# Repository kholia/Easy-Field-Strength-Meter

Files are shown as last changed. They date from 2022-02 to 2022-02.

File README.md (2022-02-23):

### Easy-Field-Strength-Meter

Jan-2022 UPDATE: v2 is published which works much better.

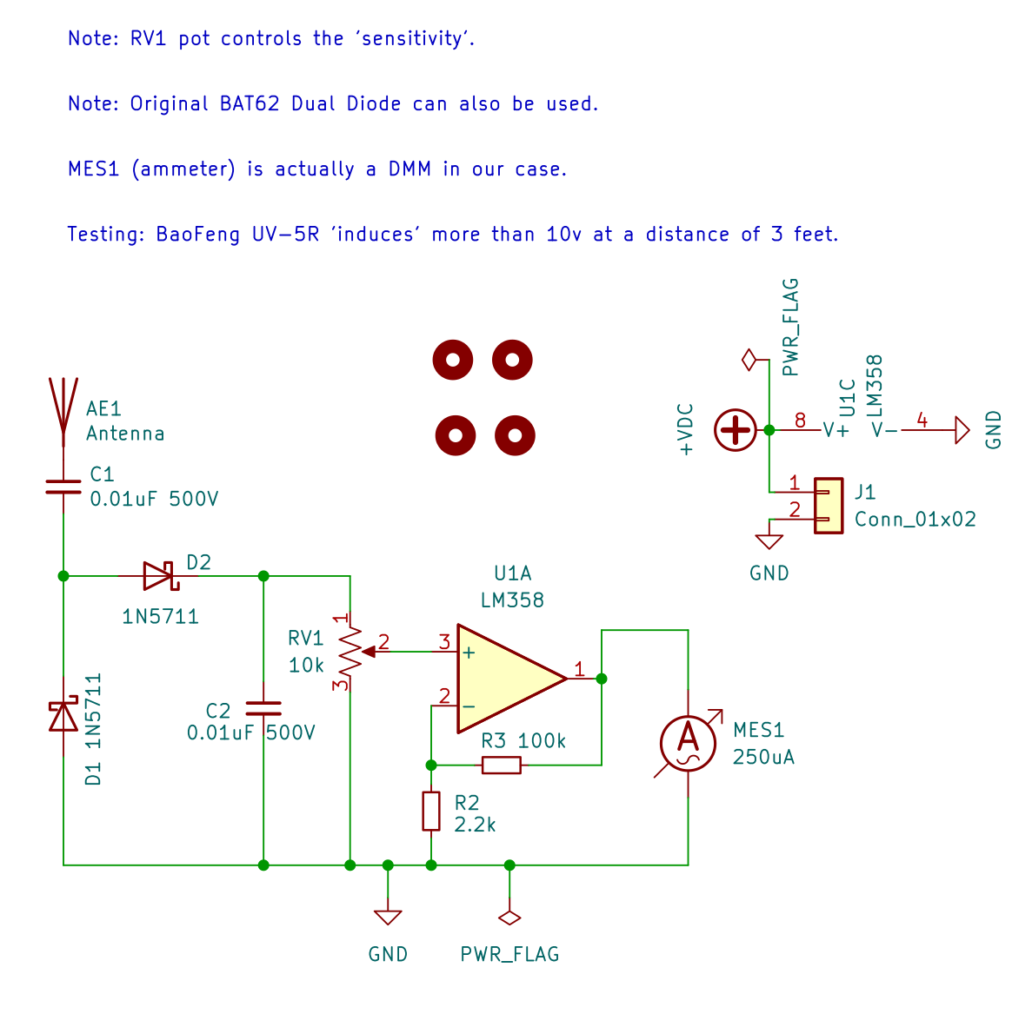
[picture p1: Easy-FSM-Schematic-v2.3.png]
Schematic v2


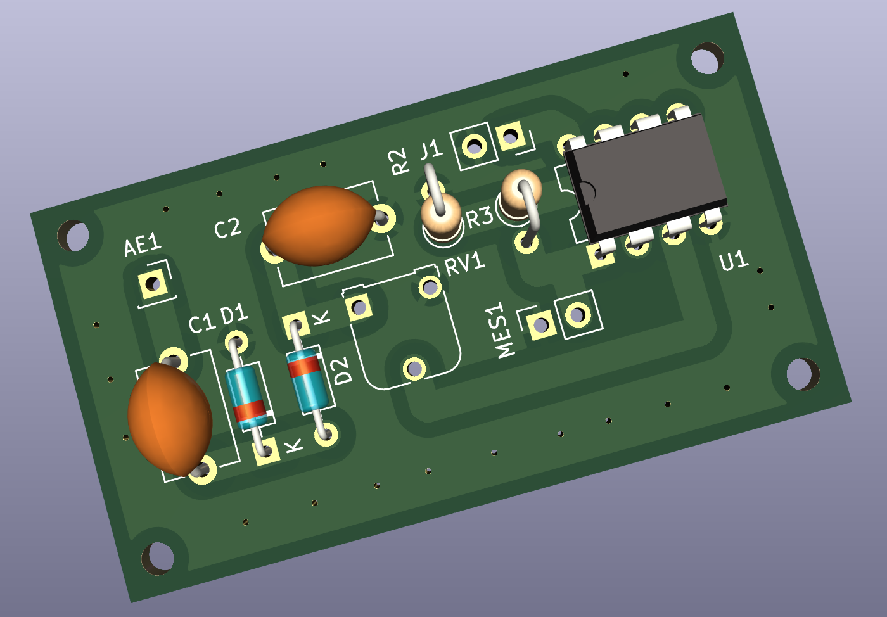
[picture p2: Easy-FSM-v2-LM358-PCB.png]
PCB Rendering v2


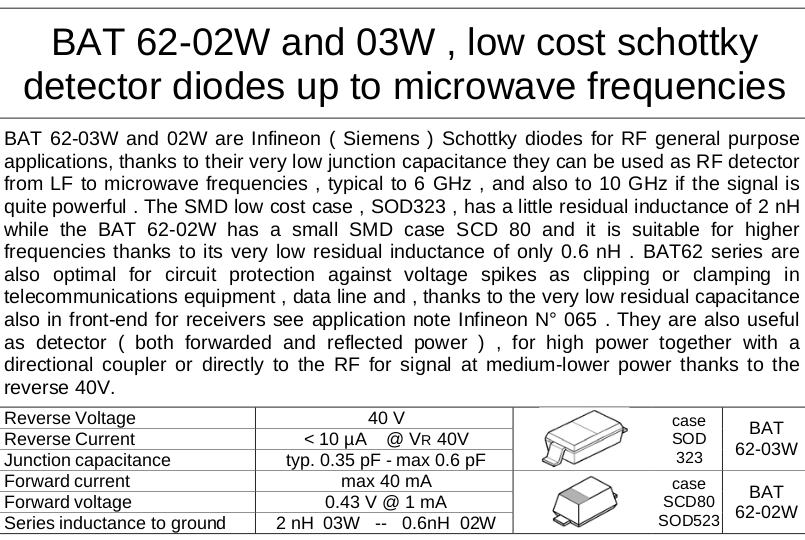
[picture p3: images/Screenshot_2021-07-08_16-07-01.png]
BAT62 is best for HAM purposes


My old FSM build:

My Build 0

Testing the FSM using a common BaoFeng VHF+UHF handie:

My Build 1

'1N60' diodes work fine too:

My Build 2

Note: This particular build is using "1N60" diodes from https://www.electronicscomp.com/.
Their "1N34A Glass Type" diodes are also OK but are less sensitive.

#### Suitable Diodes

- 1N5711 diode - original from Semikart - preferred

- BAT62 Dual Schottky Diode (Detector Diode)

- "1N60" diode

- "1N34A" diode

- BAT54S - there is not much literature around this - avoid?

#### Tips

For detecting milliwatt(s) range of power, a SDR device (RTL-SDR / HackRF One /
Airspy Discovery+) works really well.

#### BOM

- 2 x 1N60 diodes *or* 1N5711 (preferred)
- 1 x 10k or 25k Potentiometer
- 2 x 0.01uF (10 nF) Non-Polar Capacitor, 500V
- 1 x LM358 (for v2)
- 1 x 100k, 1 x 2.2k Metal Film Resistors (for v2)
- 2 x Male banana plugs
- 1 x 1 or 2 inches of flexible electrical wire ("antenna")
- 1 x Wire-loop-roll works nicely for detecting HF RF power
- 2 x Few inches of PVC coated electrical wire (for connections to DMM)
- 1 x DMM
- 1 x 0.05uF Non-Polar Capacitor, 47nF is fine too (v1)
- 1 x 470pF Non-Polar Capacitor (v1)

#### BOM Sources

- https://www.semikart.com/ (BAT 62 Dual Diode - BAT62E6327HTSA1, 1N5711)

- https://projectpoint.in/ (High voltage non-polar capacitors, pots, connectors)

- https://projectpoint.in/ ("10nF 2k", "470pF 2kV", "47nF 630V")

- https://www.electronicscomp.com/ ("germanium" diodes, misc)

- https://www.electroncomponents.com/ ("germanium" diodes, misc)

- https://www.electronicscomp.com/1n34-germanium-diode-india - the displayed pic (looks like "zener") is not correct - ignore it. This actually is of "Glass Type DO-7" type.

- https://www.electronicscomp.com/1n60-germanium-diode-india?search=1n60 - this is not "glass type" but works better than their "glass type 1N34" one. This seems to be a DO-35 package.

- https://www.probots.co.in/ (project boxes/cases)

#### References

- [Radio Prepper's YouTube video - Building a Field Strength Meter.](https://www.youtube.com/watch?v=WfkNoV0a64U)

- [Schottky diodes selection guide](http://www.skoots.yolasite.com/resources/A.pdf) - superb!

- [Infineon - RF and microwave power detection with Schottky diodes](https://www.infineon.com/dgdl/Infineon-AN_1807_PL32_1808_132434_RF%20and%20microwave%20power%20detection%20-AN-v01_00-EN.pdf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) - lovely

- https://www.pasternack.com/t-calculator-power-conv.aspx (Watts to Volts)

- https://www.huyettm.net/field-strength-meter.html

- http://www.circuitdiagram.org/field-strength-meter-fsm.html

- https://www.instructables.com/id/RF-Meter-for-Multimeter/

- https://eu.mouser.com/images/vishay/images/do35.jpg

- http://www.w1air.com/images/RFDrivenOnAirIndicator.pdf (reference for v2)

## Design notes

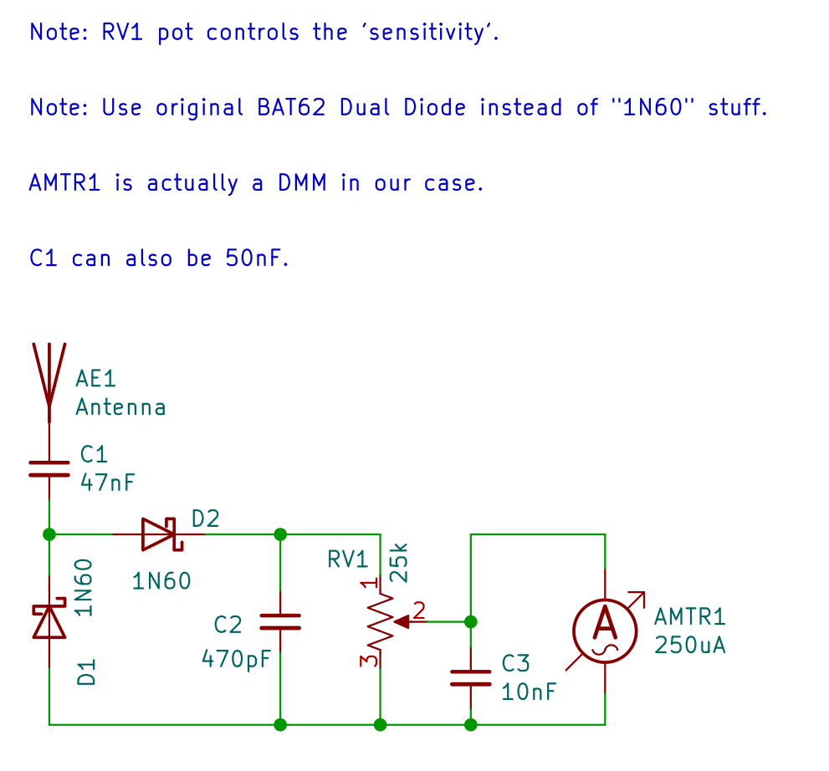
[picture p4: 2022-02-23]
Easy-FSM-Schematic.png

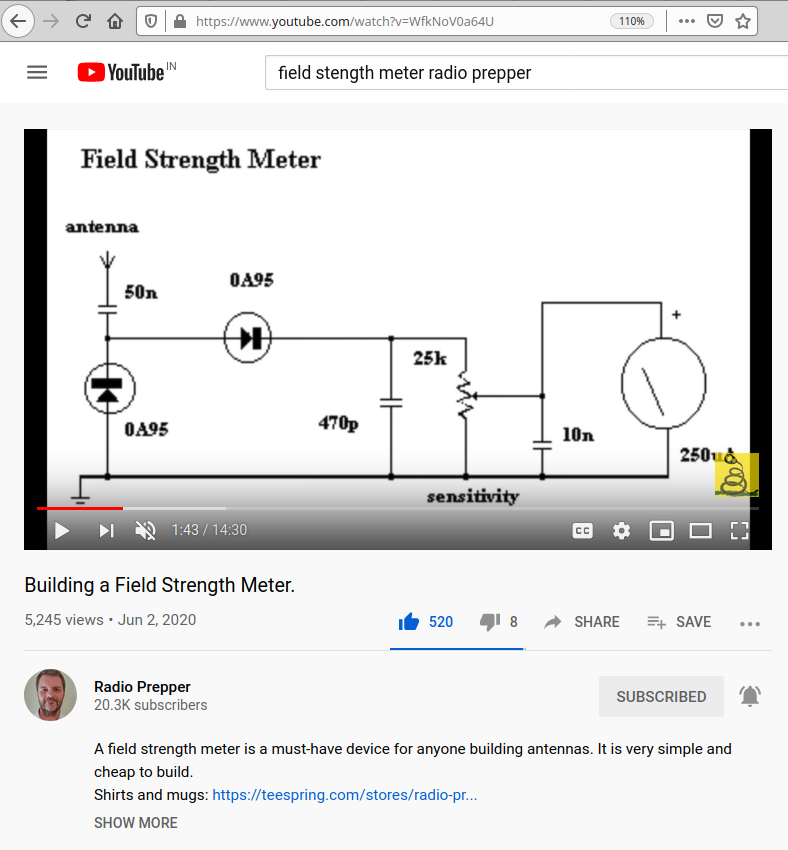
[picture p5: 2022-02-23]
images/USE THIS DESIGN - Screenshot_2020-07-14_19-36-46.png

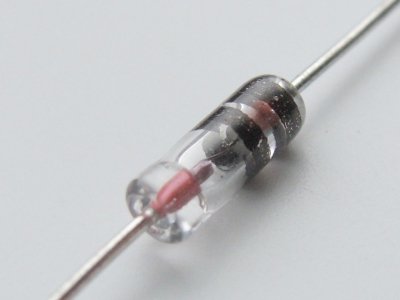
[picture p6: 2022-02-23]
images/1N34A 1N34 Germanium Diode DO-7.jpg

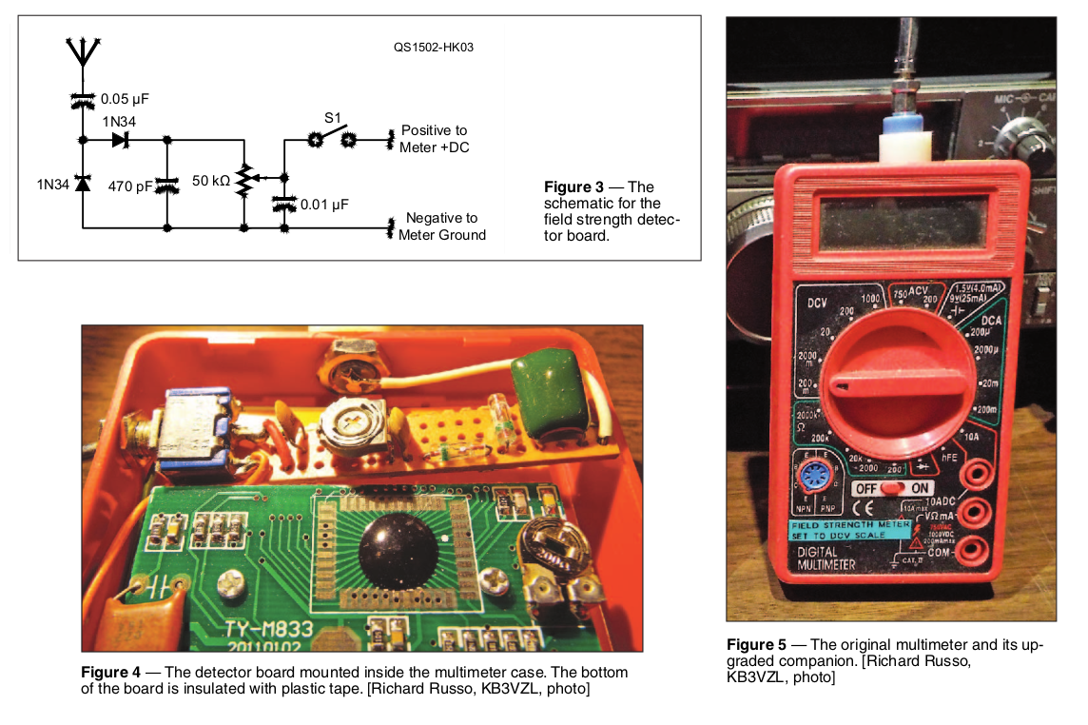
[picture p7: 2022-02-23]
images/QST Feb-2015 FSM.png

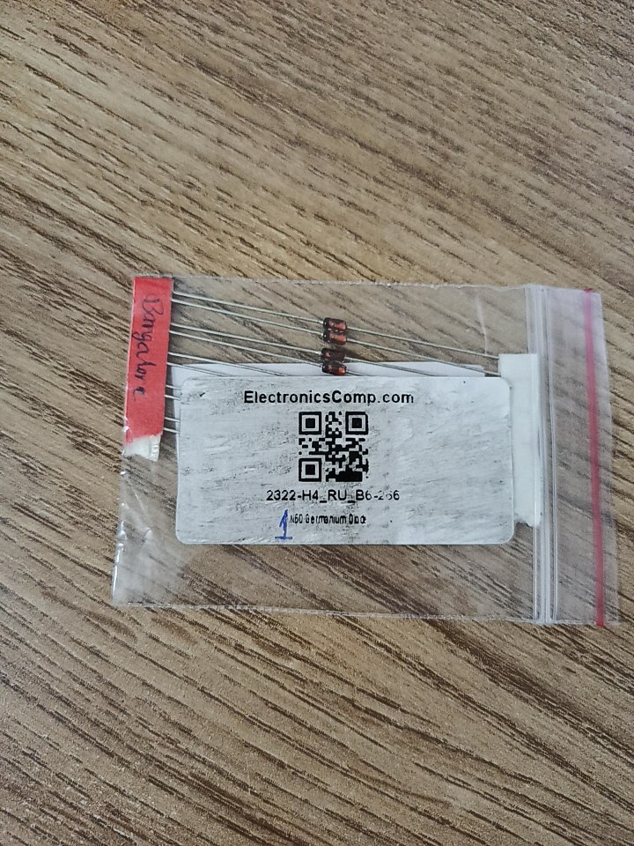
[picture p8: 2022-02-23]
images/"1N60" - 2021-04-03 15.50.00.jpg

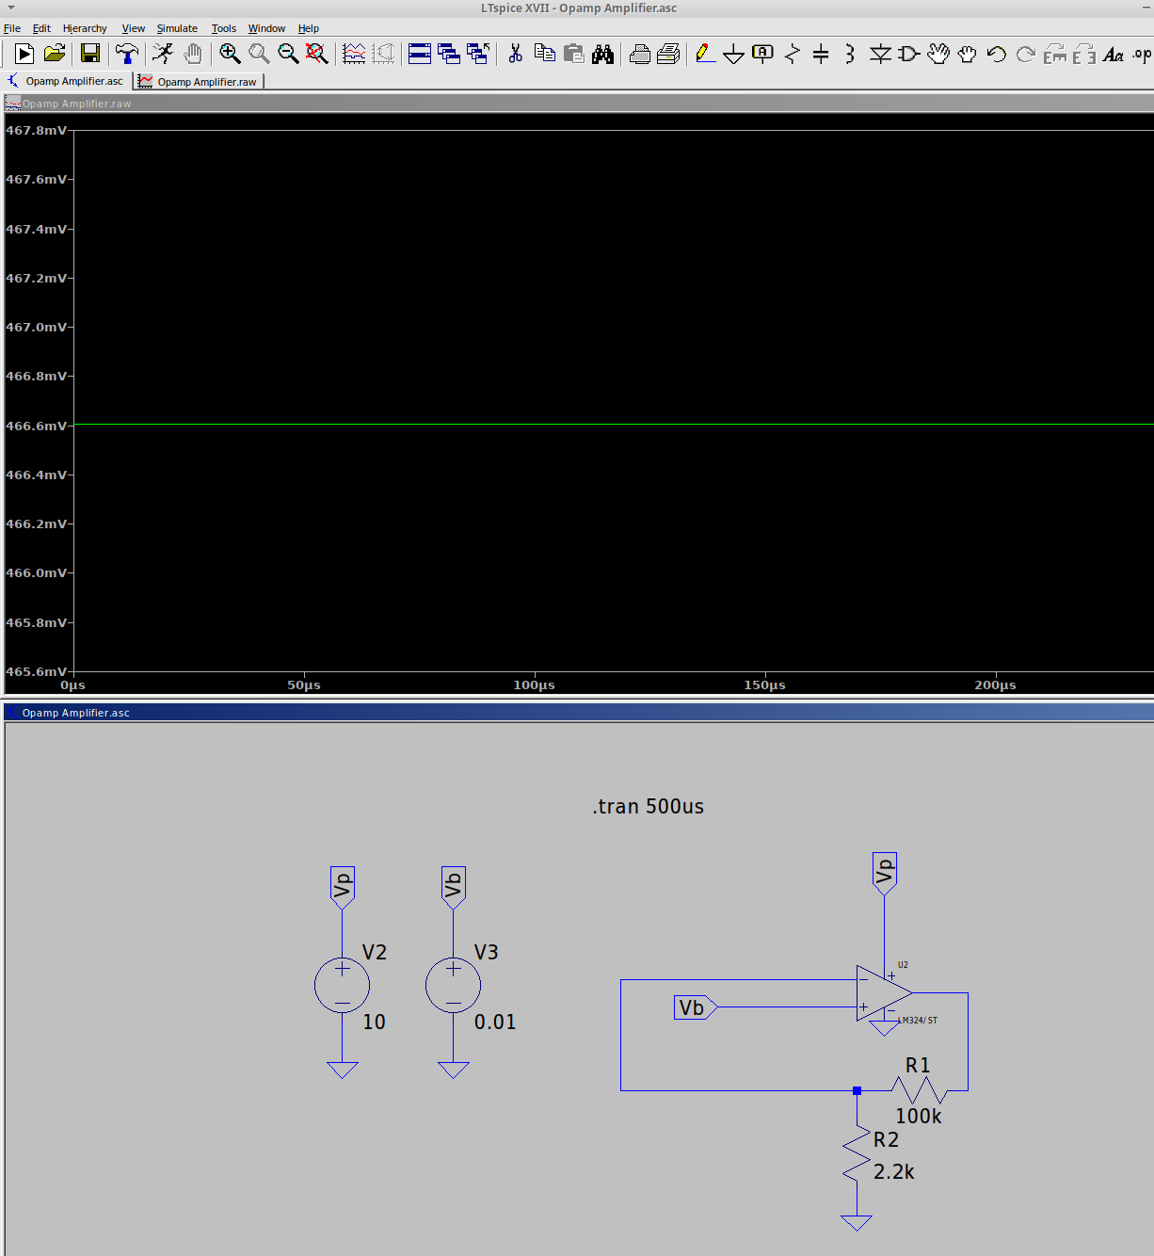
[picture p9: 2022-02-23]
Simulations/Screenshot_2022-01-05_14-53-56.png

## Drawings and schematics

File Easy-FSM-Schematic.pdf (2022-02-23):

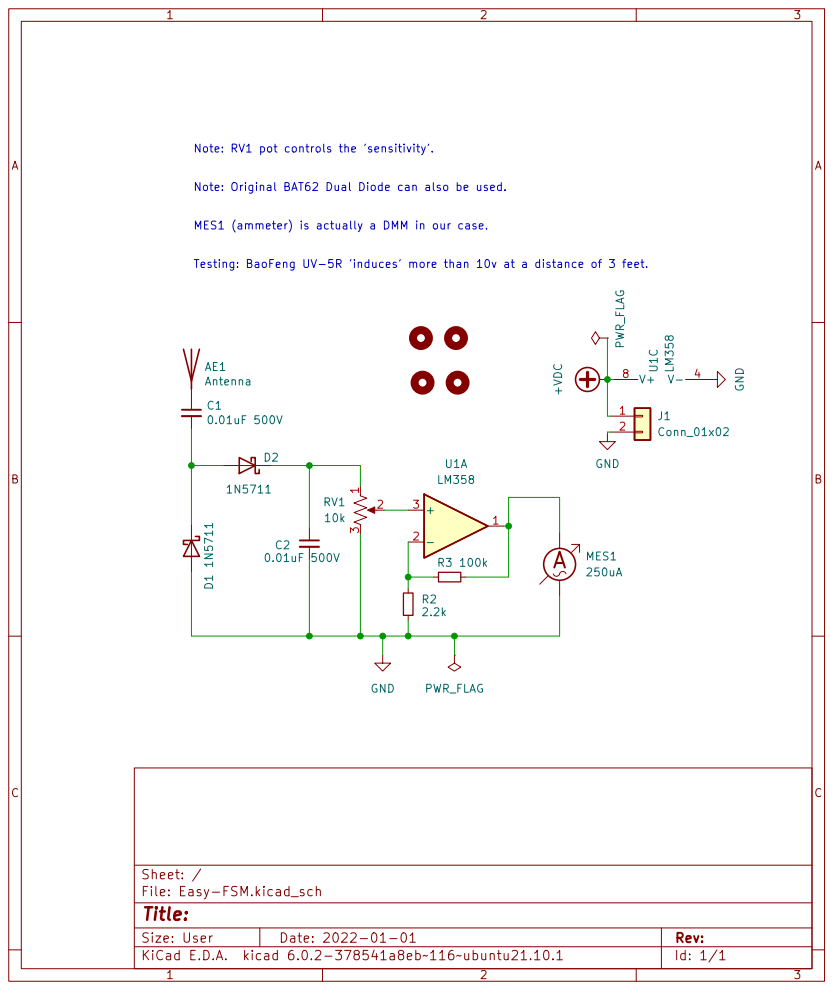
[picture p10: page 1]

Note: RV1 pot controls the 'sensitivity'.

Note: Original BAT62 Dual Diode can also be used.

MES1 (ammeter) is actually a DMM in our case.

Testing: BaoFeng UV-5R 'induces' more than 10v at a distance of 3 feet.

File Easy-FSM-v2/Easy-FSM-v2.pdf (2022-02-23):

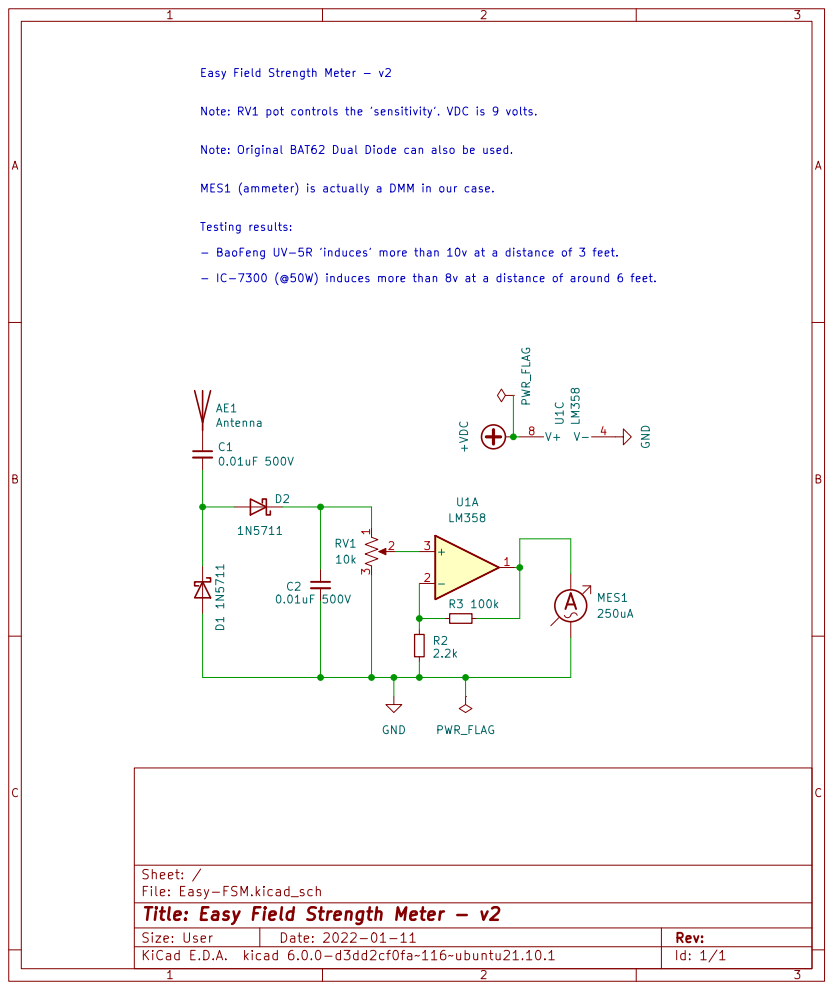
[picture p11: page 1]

Easy Field Strength Meter - v2

Note: RV1 pot controls the 'sensitivity'. VDC is 9 volts.

Note: Original BAT62 Dual Diode can also be used.

MES1 (ammeter) is actually a DMM in our case.

- BaoFeng UV-5R 'induces' more than 10v at a distance of 3 feet.

- IC-7300 (@50W) induces more than 8v at a distance of around 6 feet.

Id: 1/1 Title: Easy Field Strength Meter - v2

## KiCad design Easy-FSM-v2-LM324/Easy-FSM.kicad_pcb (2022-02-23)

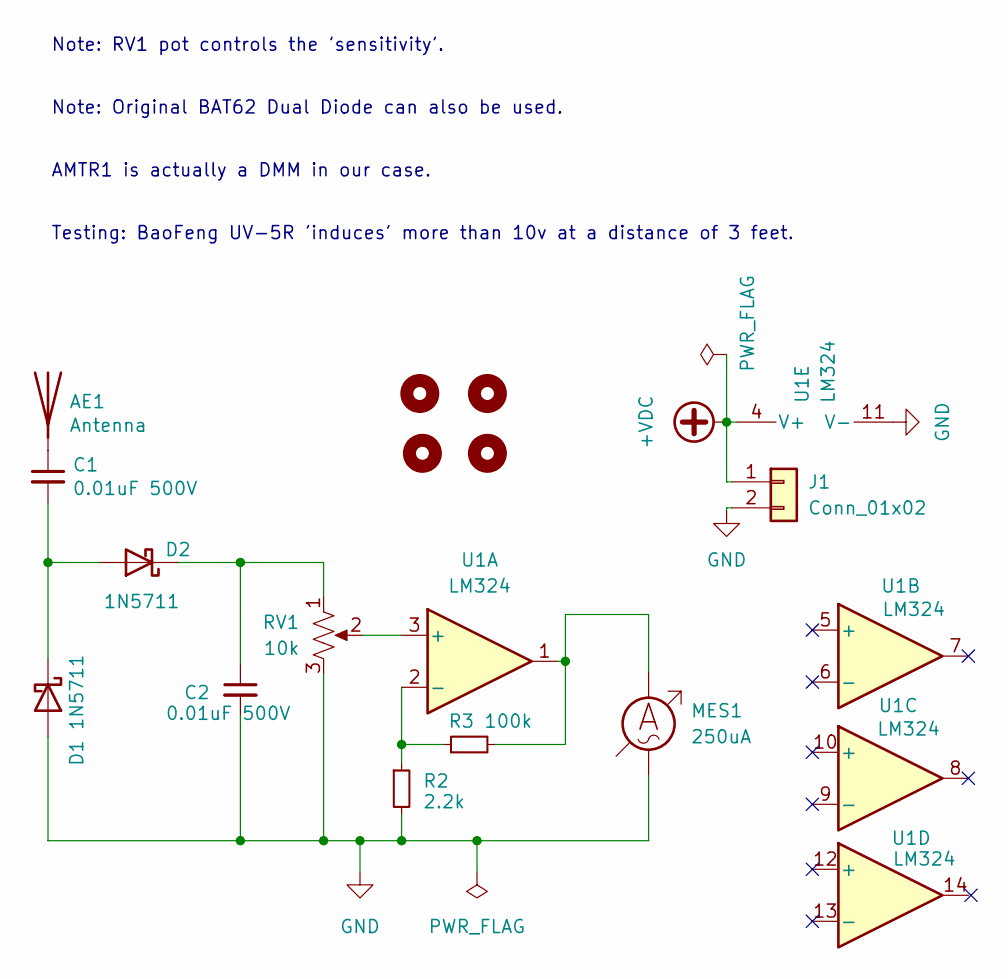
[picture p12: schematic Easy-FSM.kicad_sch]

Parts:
AE1: Antenna; PinSocket_1x01_P2.54mm_Vertical
C1, C2: 0.01uF 500V; C_Disc_D7.5mm_W5.0mm_P7.50mm
D1, D2: 1N5711; D_DO-35_SOD27_P7.62mm_Horizontal
H1, H2, H3, H4: MountingHole; MountingHole_2.2mm_M2
J1: Conn_01x02; PinSocket_1x02_P2.54mm_Vertical
MES1: 250uA; PinSocket_1x02_P2.54mm_Vertical
R2: 2.2k; R_Axial_DIN0207_L6.3mm_D2.5mm_P2.54mm_Vertical
R3: 100k; R_Axial_DIN0207_L6.3mm_D2.5mm_P2.54mm_Vertical
RV1: 10k; Potentiometer_Runtron_RM-065_Vertical
U1: LM324; DIP-14_W7.62mm

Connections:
+VDC: J1.1, U1.4 (V+)
GND: C2.2, D1.2 (A), J1.2, MES1.1, R2.2, RV1.3, U1.11 (V-)
unnamed: AE1.1 (A), C1.1
unnamed: C1.2, D1.1 (K), D2.2 (A)
unnamed: C2.1, D2.1 (K), RV1.1
unnamed: MES1.2, R3.2, U1.1
unnamed: R2.1, R3.1, U1.2 (-)
unnamed: RV1.2, U1.3 (+)

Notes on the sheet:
Note: RV1 pot controls the 'sensitivity'. Note: Original BAT62 Dual Diode can also be used. AMTR1 is actually a DMM in our case. Testing: BaoFeng UV-5R 'induces' more than 10v at a distance of 3 feet.

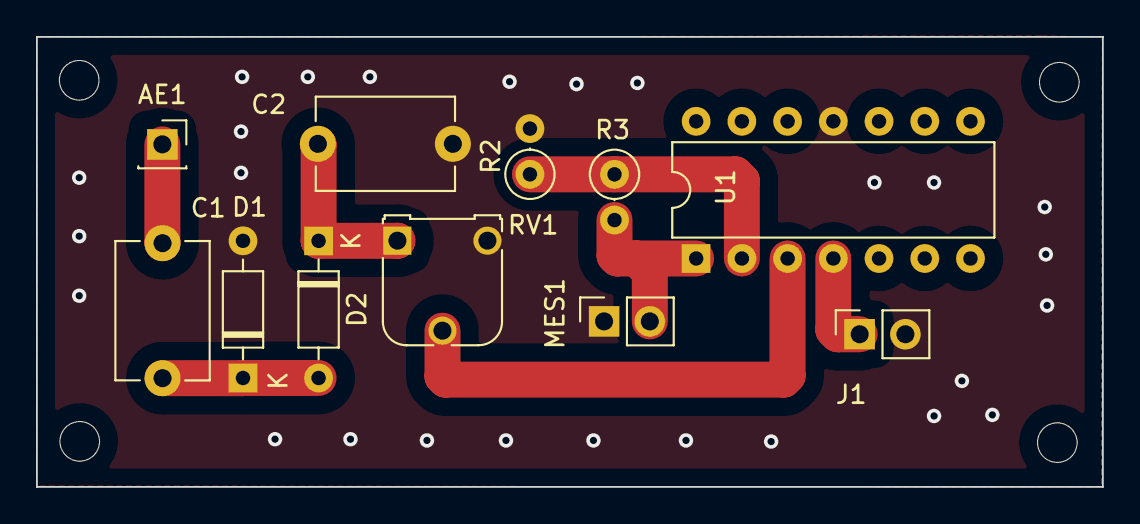
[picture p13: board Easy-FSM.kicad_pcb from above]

Board: 2 copper layers, 59.2 x 25.0 mm, 15 parts (0 on the bottom side), 8 nets.
